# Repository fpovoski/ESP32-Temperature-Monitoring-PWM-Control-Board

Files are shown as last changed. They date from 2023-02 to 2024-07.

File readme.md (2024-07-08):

# VERSION 2.1 UPDATED WITH NEW FEATURES 
### BUY - https://www.tindie.com/products/28875/

## Description
ESP32 based board for temperature monitoring/PWM fan control/addressable LED control in 3D printer enclosures, audio-visual racks, and computer/networking racks. This ESP32 board features, the powerful ESP-WROOM-32E module, with integrated WiFi and Bluetooth functionality (BR/EDR/BLE). The ESP32 is a chip designed with TSMC ultra-low power management technology. The proven ESP32-D0WD-V3 chip is located in the core of the developed module. This board has a USB-C interface for download of firmware and power during development. The board is flashed with an ESPHome image to allow immediate inclusion onto your WiFi network and OTA programming. It also has headers that allow use with conventional D1 Mini style daughter boards and is therefore pin compatible with most accessories. The board has a JST SH connector with I2C and selectable (3.3/5V) power and ground compatible with Adafruit's STEMMA QT/ Sparkfun Qwiic sensors. With optional JST SH to JST PH cable, it also supports STEMMA and Grove interfaces This board also has four Molex KK (PC fan style) that has one 5v driven output, one 5v tolerant input, in addition to fan (typ. 12v) power and ground for 4.5+ amps per connector and up to 10 amps for all four connectors. It also has two, 3-pin screw connector for one-wire devices, each with 3.3v power and ground.

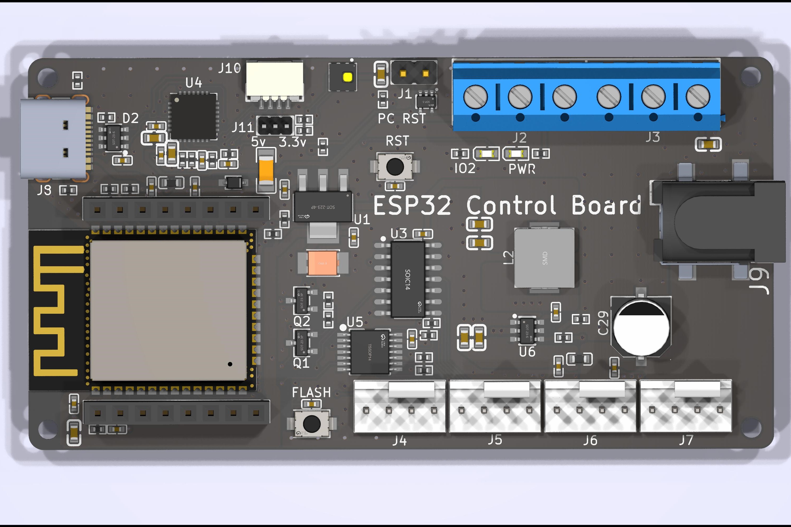
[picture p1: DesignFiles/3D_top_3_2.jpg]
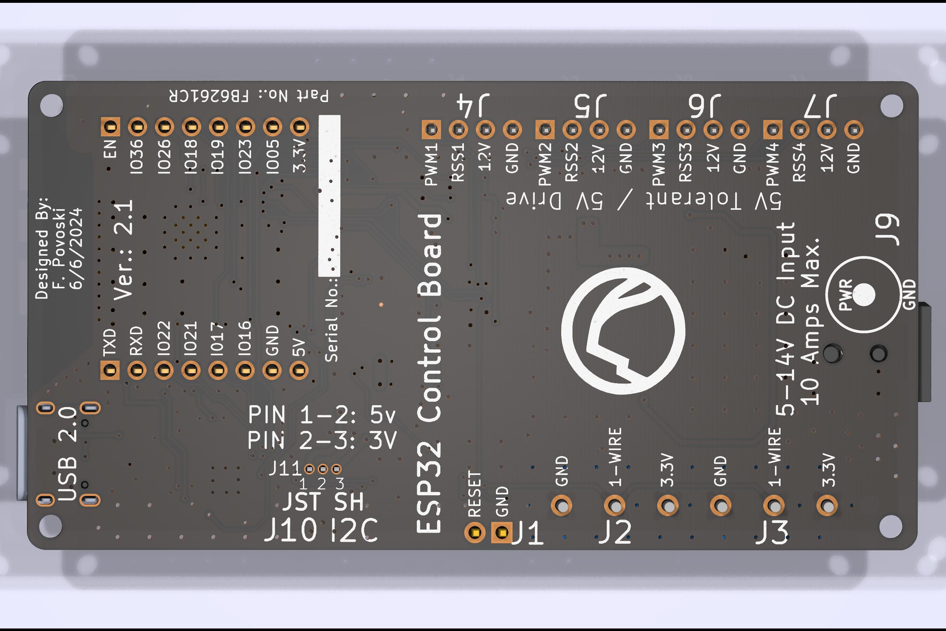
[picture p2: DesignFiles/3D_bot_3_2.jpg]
 

## Specifications:

* Size: 84mm x 44mm with 2mm mounting holes
* Processor: ESP32 on ESP32-WROOM-E module with WiFi and BT V4.2
* Power Input: 12v @ 10 amps max via 5.5mm x 2.1/2.5mm barrel connector or 5v via USB-C connector.
* 10 amp input power.
* On Board Regulation: 5v @ 2 amps switching regulator, 3.3v @ 1.0 amp.
* Onboard AHT20 Temperature and Humidity Sensor.
* Input/Output: One 5v tolerant input (1k pullup) and one 5v driven output, with 12V power (4.5+ amps per conn.) and ground on four, four-pin Molex KK series connectors. Compatible with most PWM PC style fans with speed return. Of course other use cases for these interfaces such as driving LED strings are available.
* I/O: Two screw down three position headers with common one-wire interface as well as 3.3v power and ground.
* I/O: USB 2.0 via USB-C connector using the CP2102N.
* I/O: Standard WEMOS daughter interface on two 1x8 pin headers.
* I/O: JST SH connector w/ I2C/PDM interface 3.3v/5.0v selectable power (compatible with Adafruit's STEMMA QT/ Sparkfun Qwiic sensors).
* I/O: Two-pin 2.54mm header with buffered open collector output.
* Add-ons: Relay - uses GPIO18 mapped to the WEMOS daughter interface.

Please note that some fans especially older ones do not conform with the "Intel 4-Wire PWM Controller Fans" specification. These fans do not stop spinning with a PWM duty cycle of 0% but spin at their minimum RPM. Below is a list of some of these fans currently known to us:
* Corsair 31-002319.
* Delta QFR1212GHE (and very possibly other Delta fans).

A 3D printed enclosure is also available: https://www.tindie.com/products/29364/

## Setup and Configuration

* DO NOT ATTEMPT TO POWER FANS FROM USB-C. Supplied power (5v-14V) to barrel connector
needs to match the voltage of the PWM fan (or other device) you are driving. Board has an onboard
self-resetting flex fuse rated at 12 amps.

* To place on WiFi network use 2.4G phone to connect to "AVFAN1 Fallback Hotspot" with password "esphome1" ("trek6666" in some factory flashes). Once connected to your WiFi network, to access the webpage of
the device browse to http://avfan1.local

* Device is flashed with an exmaple ESPhome binary image that has manual control over fans 
and automatic control which can be enabled based the target temperature setting.  Four temperature
sensors control each of the four PWM fan connectors.
Flashed binary image  has "api:" disabled, MQTT enabled.

* For customization, downlaod the example (flashed) code from 
https://github.com/fpovoski/ESP32-Temperature-Monitoring-PWM-Control-Board/blob/main/ESPhome/avfan1.yaml

* Also update WiFi and MQTT server credentials as required.

* Flash over USB or ethernet. To flash over USB use ESPhome Web Flasher https://web.esphome.io/
with the device powered and connected to your host machine.

* For Dallas style sensors (board preprogrammed with logger level: DEBUG), to get device ID follow
Seach for them in the initial logger output when connected to the USB port using ESPhome Web Flasher.
  - Connect your Dallas sensors with logger: DEBUG enabled (factory flash default).
  - Open the ESPHome webtool, connect to the ECB board, view the "Logs" window, hit "Reset",and search for Dallas scan addresses and replace the below addresses with your unique ones.
  - Example Scan:
  - [18:16:42][D][dallas.sensor:084]:     0x8b3ca8f64935b228 4
  - [18:16:42][D][dallas.sensor:084]:     0x783c0af6490d3628 2
  - [18:16:42][D][dallas.sensor:084]:     0xc13c01f09642c928 1
  - [18:16:42][D][dallas.sensor:084]:     0x043c6ef649772f28 3
  - dallasaddress1: "0xc13c01f09642c928"
  - dallasaddress2: "0x783c0af6490d3628"
  - dallasaddress3: "0x043c6ef649772f28"
  - dallasaddress4: "0x8b3ca8f64935b228"  

* For adding Wemos style boards (i.e., relay) with the case installed  use the long (19mm) provided pins.

## Connector to GPIO Mapping.

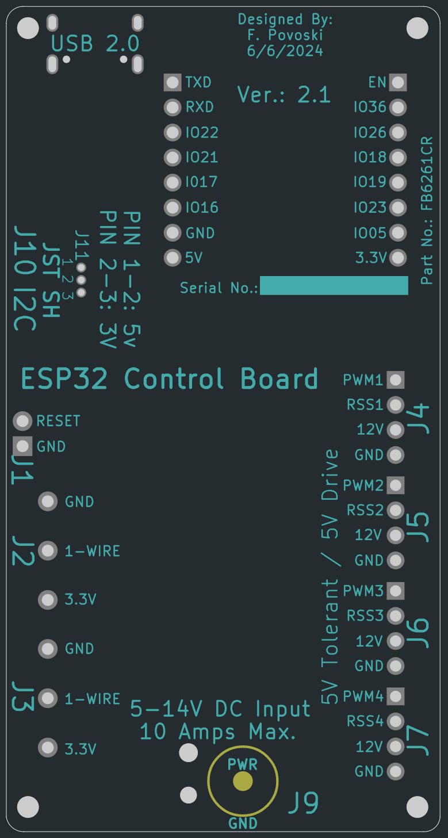
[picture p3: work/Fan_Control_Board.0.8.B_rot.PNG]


### Buffer Open-Collector Ouput on 2.54mm Header J3
| CONNECTOR | PIN1 | PIN2 |
| --- | ---- | ---- |
| J1 | GND | IO26(OC) |

### Dallas One-wire Screw Terminal Connectors J1-J3
| CONNECTOR | PIN1 | PIN2 | PIN3 |
| --- | ---- | ---- | ---- |
| J2 | +3.3V | IO27 | GND |
| J3 | +3.3V | IO27 | GND |

### PWM Fan/LED KK Style Connectors J4-J7
- PIN3 - Input 5V tolerant with 1K pullup resistor
- PIN4 - Output 5V drive.
- PWR - Matches input voltage on J9. Rated to 4.5 amps.
			
| CONNECTOR | PIN1 | PIN2 | PIN3 | PIN4 |
| --- | ---- | ---- | ---- | ---- |
| J4 | GND | PWR | IO33 | IO13 |
| J5 | GND | PWR | IO34 | IO14 |
| J6 | GND | PWR | IO35 | IO25 |
| J7 | GND | PWR | IO39 | IO32 |

### USB-C Connector J8
- USB 2.0, 5V, 2amps.

### Power Jack Connector J9
- +5-14V 12 amps max.
- Directly supplies J4-J7 PWR
- Must match your fan or LED voltage.

| CONNECTOR | Center | Perimeter |
| --- | ---- | ---- |
| J9 | GND | +5-14V | GND |

### I2C/PDM JST SH Connector J10
- Direct Interface for STEMMA and QWIIC boards typically using I2C or PDM.
- Available for other functions than I2C or PDM.
- PWR - Either +3.3V or +5.0V selectable by J11.

| CONNECTOR | PIN1 | PIN2 | PIN3 | PIN4 |
| --- | ---- | ---- | ---- | ---- |
| J10 | GND | PWR | IO21/SDA/PDMDATA | IO22/SCL/PDMCLK |

### Power Selection J11
- Voltage level selection for J10.
- Jumper Pin 1 and 2: +5V
- Jumber Pin 3 and 2: +3.3V

| CONNECTOR | PIN1 | PIN2 | PIN3 |
| --- | ---- | ---- | ---- |
| J11 | +5V | J10.1 | +3.3V |
  
### WeMos D1 Mini Plug P1 and P2

| CONNECTOR | PIN1 | PIN2 | PIN3 | PIN4 | PIN5 | PIN6 | PIN7 | PIN8 |
| --- | ---- | ---- | ---- | ---- | ---- | ---- | ---- | ---- |
| P1 | +5V | GND | IO16 | IO17 | IO21 | IO22 | RXD/IO03 | TXD/IO01 |
| P2 | +3.3V | IO05 | IO23| IO19 | IO18 | IO26 | IO36 | EN |

## Customer Created Projects Utilizing The ECB
Ando Roots: https://www.printables.com/model/702072-1u-rack-fan-shelf

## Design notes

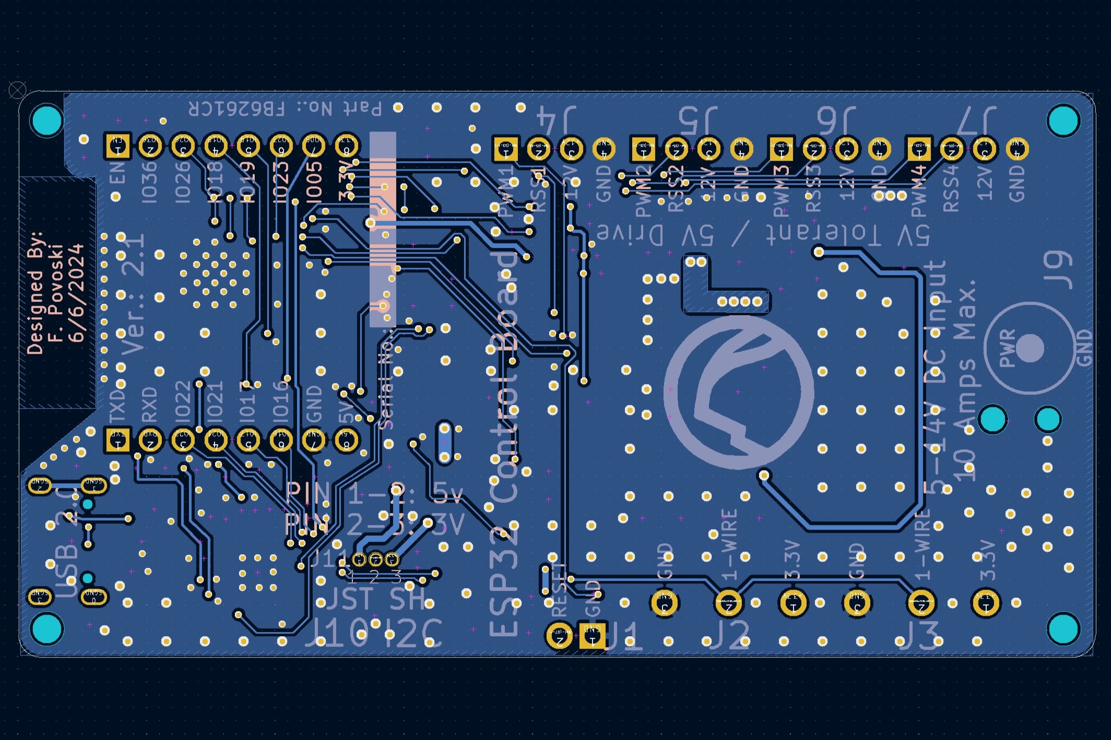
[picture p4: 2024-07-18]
DesignFiles/PCB_bot_3_2.jpg

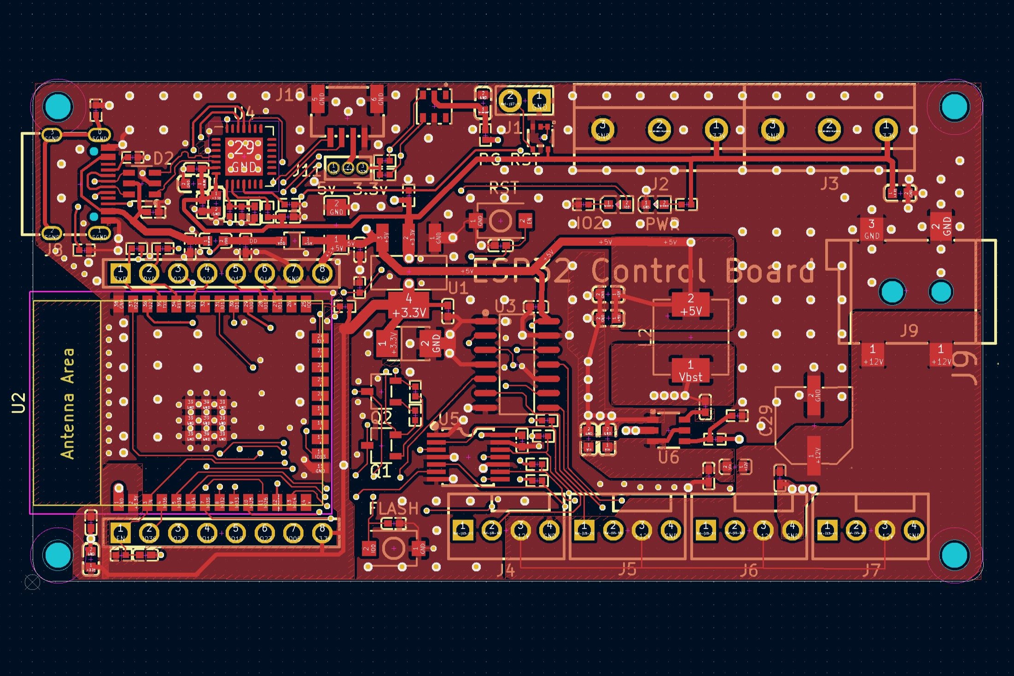
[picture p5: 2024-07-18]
DesignFiles/PCB_top_3_2.jpg

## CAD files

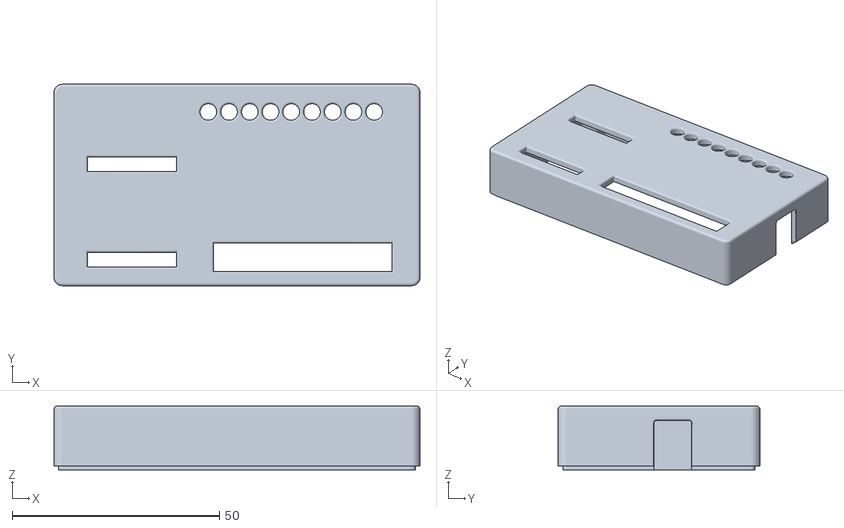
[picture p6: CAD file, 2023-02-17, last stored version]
box 13 top.stl
88.3 x 48.6 x 15.4

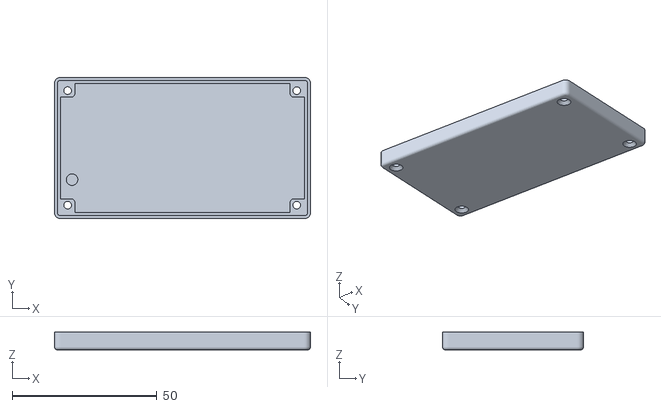
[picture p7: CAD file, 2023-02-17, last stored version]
box 13 bot.stl
88.3 x 48.6 x 6.10

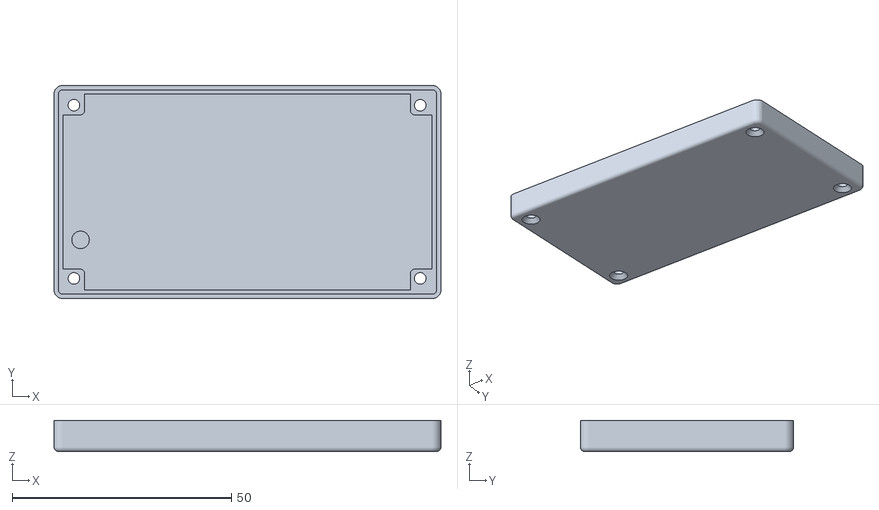
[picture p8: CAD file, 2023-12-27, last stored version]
Enclosure/ECB_bot._V2.stl
88.3 x 48.6 x 7.10

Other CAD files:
Enclosure/ECB_Enclosure_V2.step
Enclosure/NewBoard1 Box.step
Enclosure/ECB_top_V2.stl
Enclosure/Box-Top.stl
Enclosure/ECB_Enclosure_V2.3mf

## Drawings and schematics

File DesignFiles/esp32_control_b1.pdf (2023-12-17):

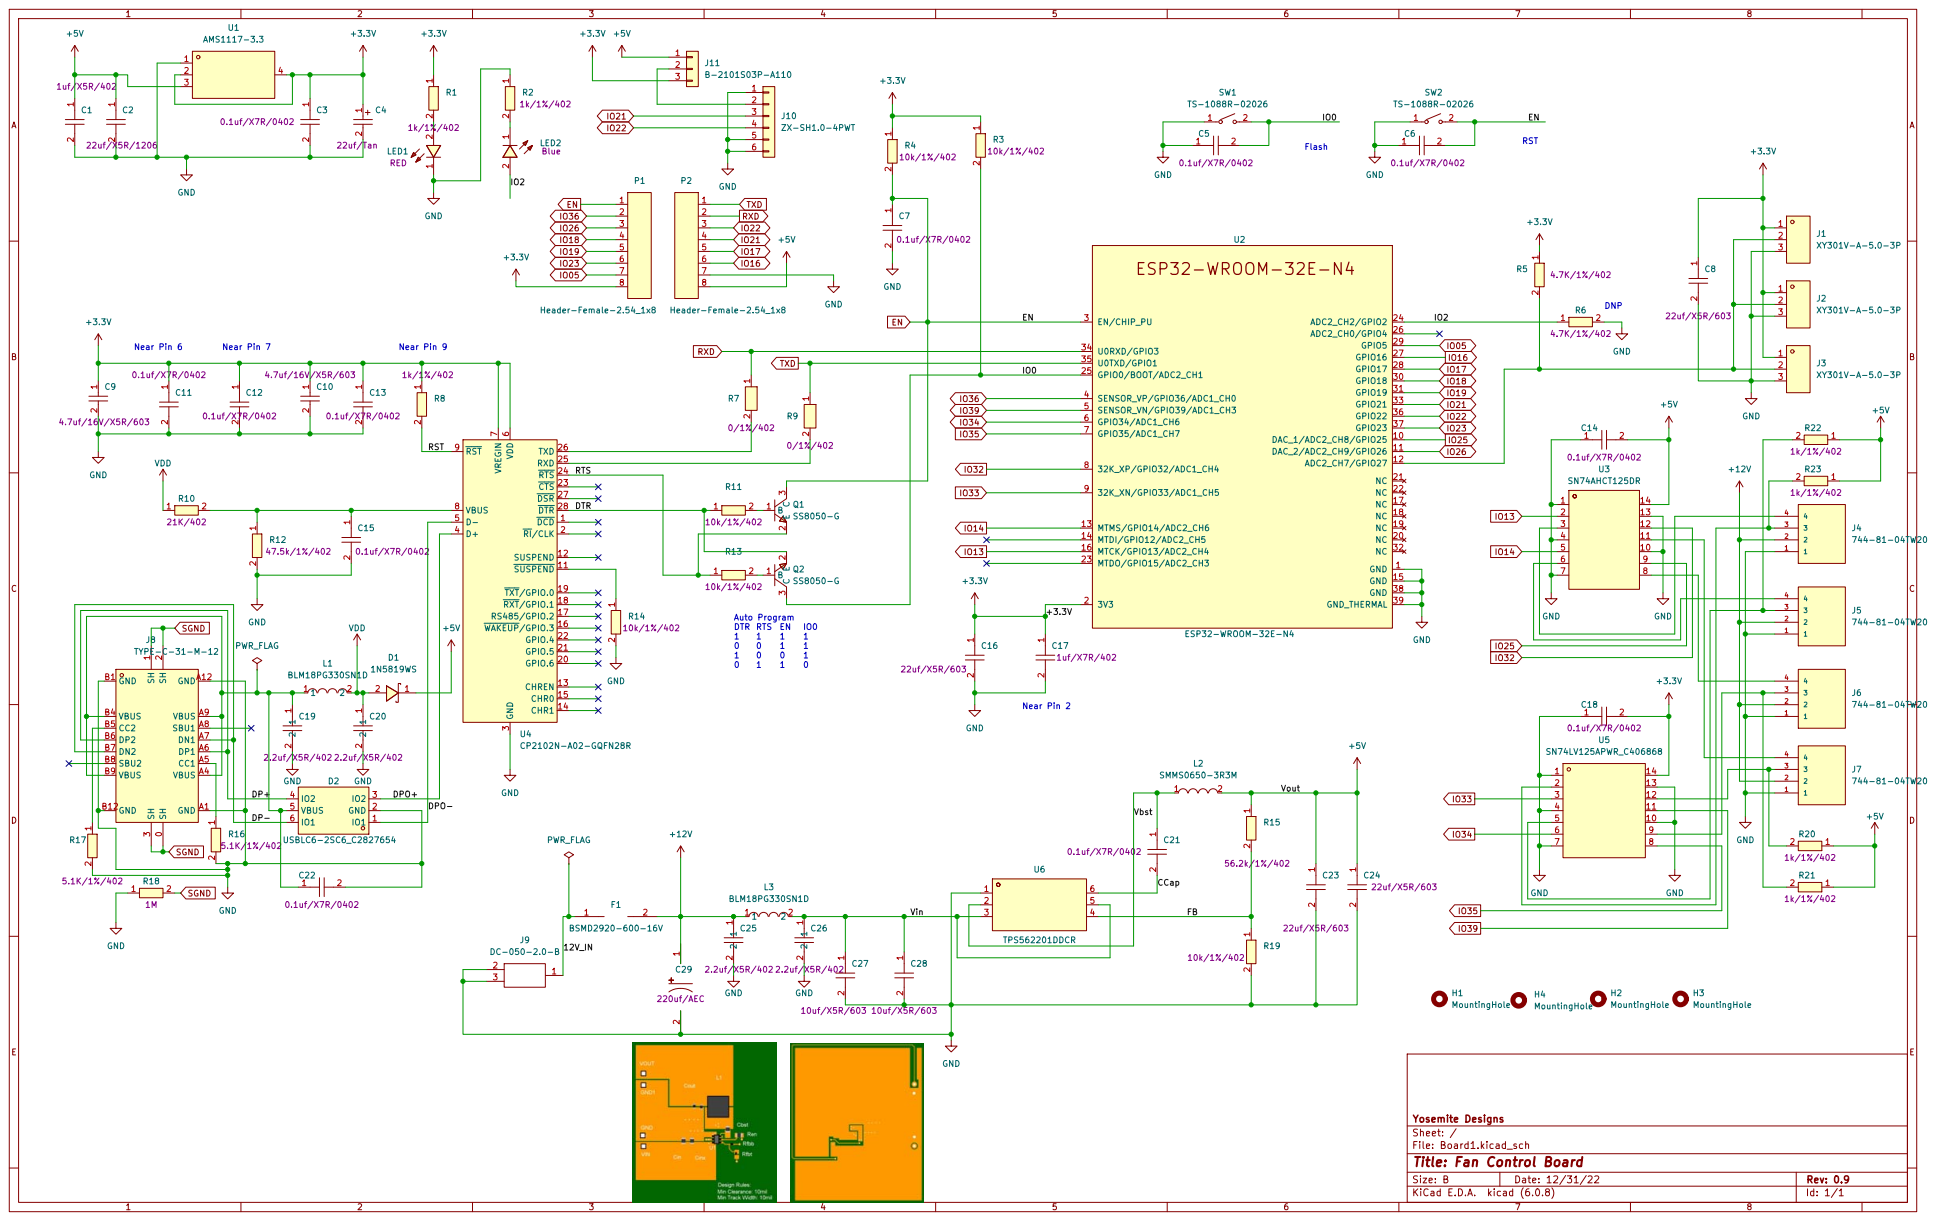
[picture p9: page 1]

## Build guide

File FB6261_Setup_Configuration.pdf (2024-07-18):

## ESP32 Control Board V2.1, Part No. FB6261

For email support: esp32andmore@gmail.com. For text/telephone/WhatsApp support: 1.585.310.1770 See: https://github.com/fpovoski/ESP32-Temperature-Monitoring-PWM-Control-Board

## Setup and Configuration

* Home Assistant Configuration
api:
encryption:
key: "itqzvhZMJj8wuTJX0GTOuL/ffESFROzUlmcO0u2+sfo=" #use your own HA generated Key

* DO NOT ATTEMPT TO POWER FANS FROM USB-C. Supplied power (5v-14V) to barrel connector needs to match the voltage of the PWM fan (or other device) you are driving. Board has an onboard self-resetting flex fuse rated at 10 amps.

* To place on WiFi network use 2.4G phone to connect to "AVFAN1 Fallback Hotspot" with the password "esphome1" ("trek6666" in some factory flashed). Once connected to your WiFi network, to access the webpage of the device browse to http://avfan1.local

* Device is flashed with an example ESPHome binary image that has manual control over fans and automatic control based on the measured temperature and the target temperature setting. Four temperature sensors control each of the four PWM fan connectors. The lambda function in the Dallas Platforms calculates and sets the corresponding fan speed. Flashed binary image has "api:" enabled, MQTT disabled.

* For customization, download the example (flashed) code from https://github.com/fpovoski/ESP32-Temperature-Monitoring PWM-Control-Board (avfan1.yaml). Also update WiFi and MQTT server credentials as required.

* Flash over USB or ethernet. To flash over USB use ESPHome Web Flasher https://web.esphome.io/ with the device powered and connected to your host machine.

* For Dallas style sensors (board preprogrammed with logger level: DEBUG), to get device ID follow
Seach for them in the initial logger output when connected to the USB port using ESPhome Web Flasher. See, avfan1.yaml for instructions.

* For adding Wemos style boards (i.e., relay) with the case installed use the long (19mm) provided pins.

* For voltage selection of JST SH connector (J10) use J11 (+5V - J11.1 to J11.2, +3.3V - J11.3 to J11.2). Despite being able to supply 5v power make sure all your I2C devices are all using 3.3v signaling as it is not a 5v tolerant bus.

Connector to GPIO Mapping
GPIO PIN | CONNECTOR | Input | Output Notes
0 | 25 | | PU | OK | outputs PWM at boot, must be LOW to enter flashing mode
1 | 35 | P2.1 | TX pin OK | debug output at boot
2 | 24 | | OK | OK | conn. to on-board LED, left floating or LOW to enter flashing mode
3 | 34 | P2.2 | OK | RX pin HIGH at boot
4 | 26 | | OK | OK
5 | 29 | P1.7 | OK | OK | outputs PWM signal at boot, strapping pin
6 | 20 | | x | x | connected to the integrated SPI flash
7 | 21 | | x | x | connected to the integrated SPI flash
8 | 22 | | x | x | connected to the integrated SPI flash
9 | 17 | | x | x | connected to the integrated SPI flash
10 | 18 | | x | x | connected to the integrated SPI flash
11 | 19 | | x | x | connected to the integrated SPI flash
12 | 14 | | OK | OK | boot fails if pulled high, strapping pin
13 | 16 | PWM1-(J4) | OK | OK
14 | 13 | PWM2-(J5) | OK | OK | outputs PWM signal at boot
15 | 23 | | OK | OK | outputs PWM signal at boot, strapping pin
16 | 27 | P2.6, SDA_B(AHT20, 0x38) OK | OK

17 | 28 | P2.5, SCL_B(AHT20, 0x38) OK | OK
18 | 30 | P1.4 | OK | OK
19 | 31 | P1.5 | OK | OK
20
21 | 33 | P2.4, SDA_A-(J10) | OK | OK
22 | 36 | P2.3, SCL_A(J10) | OK | OK
23 | 37 | P1.6 | OK | OK
24
25 | 10 | PWM3-(J6) | OK | OK
26 | 11 | P1.3-(J1) | OK | OK
27 | 12 | 1WIRE | OK | OK
32 | 8 | PWM4-(J7) | OK | OK
33 | 9 | RPM1-(J4) | OK | OK
34 | 6 | RPM2-(J5) | OK | input only
35 | 7 | RPM3-(J6) | OK | input only
36 | 4 | P1.2 | OK | input only
39 | 5 | RPM4-(J7) | OK | input only
EN | 3 | P1.1
3.3 | 2 | P1.8
GND | 1 | P2.7
GND | 15
GND | 38
NC | 32
+5 | | P2.8

Open Collector 2.54mm Header Connector
CONN PIN1 | PIN2(labeled RESET)
J1 | GND | IO26

Dallas One-wire Connectors
CONN PIN1 | PIN2 | PIN3
J2 | +3.3V | IO27 | GND
J3 | +3.3V | IO27 | GND
PWM KK Style Headers: | PIN3 - Fan Speed Input, 5V Tolerant, 1K Pullup Resistor
PIN4 - Fan PWM Output, 5V Drive
CONN PIN1 | PIN2 | PIN3 | PIN4
J4 | GND | +5/12V IO33 | IO13
J5 | GND | +5/12V IO34 | IO14
J6 | GND | +5/12V IO35 | IO25
J7 | GND | +5/12V IO39 | IO32

JST SH (STEMMA QT/QWIIC)*
CONN PIN1 | PIN2 | PIN3 | PIN4
J10 | GND | +3.3/5V IO21 | IO22

*1.27MM JUMPER HEADER: PIN1-2 -> +5V, PIN3-2 -> +3.3V
CONN PIN1 | PIN2 | PIN3
J11 | +5V | GND | +3.3V
J8 | USB2.0 on USB-C (USB can be connected when barrel connector power).
J9 | +5/12V 10 amps max. to board and fans. (5-14v range, needs to match devices on J4-J7)

P1 and P2: Standard WEMOS D1 Expansion Header

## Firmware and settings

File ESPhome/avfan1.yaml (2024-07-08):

# Four automatically controlled PWM fan outputs (J4-J7), each set by four target temperatures, maintained by four Dallas sensor's temperatures. MQTT enabled. Home Assistant API disabled. DHCP enabled.
# Other control configurations available with modification of Dallas platform LAMBDA function. Contact us at esp32andmore@gmail.com for no cost customization.
substitutions:
  devicename: avfan1
  fdevicename: AVfan1
  ip: 192.168.0.178 # For static IP adressing

  ssid: !secret wifi_ssid
  password: !secret wifi_password

  alarm_temp: "50" # Threshold for alarm when implemented
  ptemp: "20"
  itemp: "0.1"

# Connect your Dallas sensors with logger: DEBUG enabled (factory flash default).
# Open the ESPHome webtool, connect to the ECB board, view the "Logs" window, hit "Reset",
# and search for Dallas scan addresses and replace the below addresses with your unique ones.
# Example Scan
#[18:16:42][D][dallas.sensor:084]:     0x8b3ca8f64935b228 4
#[18:16:42][D][dallas.sensor:084]:     0x783c0af6490d3628 2
#[18:16:42][D][dallas.sensor:084]:     0xc13c01f09642c928 1
#[18:16:42][D][dallas.sensor:084]:     0x043c6ef649772f28 3
  dallasaddress1: "0xc13c01f09642c928"
  dallasaddress2: "0x783c0af6490d3628"
  dallasaddress3: "0x043c6ef649772f28"
  dallasaddress4: "0x8b3ca8f64935b228"


esphome:
  name: ${devicename}
  friendly_name: ${fdevicename}

  on_boot:
  - priority: 900.0
    then:
      - lambda: |-
          id(cpu_speed) = ESP.getCpuFreqMHz();

esp32:
  board: wemos_d1_mini32
  framework:
    type: arduino

preferences:
  flash_write_interval: 10min
    
wifi:
  ssid: ${ssid}
  password: ${password}
  #fast_connect: true
  #example static IP settings
  #manual_ip:
    #static_ip: ${ip}
    #gateway: 192.168.0.1
    #subnet: 255.255.255.0
    #dns1: 192.168.0.1
    #dns2: 8.8.8.8

  # Enable fallback hotspot (captive portal) in case wifi connection fails
  ap:
    ssid: ${fdevicename} Fallback Hotspot
    password: "esphome1"
    manual_ip:
      static_ip: 192.168.100.2
      gateway: 192.168.100.2
      subnet: 255.255.255.0

    
captive_portal:

ota:
  - platform: esphome
    password: "esphome1"

#safe_mode:

#mqtt:
  #broker: 192.168.0.100   # use your own MQTT server address and credentials
#  username: "john"
#  password: "trek6666"

api:
  encryption:
    key: "itqzvhZMJj8wuTJX0GTOuL/ffESFROzUlmcO0u2+sfo="  #use your own HA generated Key
  
web_server:
  port: 80

time:
  - platform: sntp
    id: current_time

debug:
  update_interval: 5s

logger:
  level: Debug

globals:
  - id: fan1_sum
    type: float
    restore_value: no
    initial_value: '0'
  - id: fan2_sum
    type: float
    restore_value: no
    initial_value: '0'
  - id: fan3_sum
    type: float
    restore_value: no
    initial_value: '0'
  - id: fan4_sum
    type: float
    restore_value: no
    initial_value: '0'
  - id: target1
    type: int
    restore_value: True
    initial_value: '26'
  - id: target2
    type: int
    restore_value: True
    initial_value: '26'
  - id: target3
    type: int
    restore_value: True
    initial_value: '26'
  - id: target4
    type: int
    restore_value: True
    initial_value: '26'
  - id: cpu_speed
    type: int
    restore_value: no
    initial_value: "0"

number:
  - platform: template
    id: set_target_temp_1
    name: ${fdevicename} Target Temp 1
    optimistic: True
    min_value: 15
    max_value: 50
    initial_value: '26'
    step: 1
    restore_value: True
    unit_of_measurement: °C
    device_class: "TEMPERATURE"
    #command_topic: ${devicename}/number/${devicename}_target_temp_1/command  #add for MQTT

  - platform: template
    id: set_target_temp_2
    name: ${fdevicename} Target Temp 2
    optimistic: True
    min_value: 15
    max_value: 50
    initial_value: '26'
    step: 1
    restore_value: true
    unit_of_measurement: °C
    device_class: "TEMPERATURE"
    #command_topic: ${devicename}/number/${devicename}_target_temp_2/command  #add for MQTT

  - platform: template
    id: set_target_temp_3
    name: ${fdevicename} Target Temp 3
    optimistic: True
    min_value: 15
    max_value: 50
    initial_value: '26'
    step: 1
    restore_value: true
    unit_of_measurement: °C
    device_class: "TEMPERATURE"
    #command_topic: ${devicename}/number/${devicename}_target_temp_3/command  #add for MQTT
    
  - platform: template
    id: set_target_temp_4
    name: ${fdevicename} Target Temp 4
    optimistic: True
    min_value: 15
    max_value: 50
    initial_value: '26'
    step: 1
    restore_value: true
    unit_of_measurement: °C
    device_class: "TEMPERATURE"
    #command_topic: ${devicename}/number/${devicename}_target_temp_4/command  #add for MQTT

  - platform: template
    id: set_alarm_temp
    name: ${fdevicename} Alarm Temp
    optimistic: True
    min_value: 15
    max_value: 80
    initial_value: ${alarm_temp}
    step: 1
    restore_value: true
    unit_of_measurement: °C
    device_class: "TEMPERATURE"
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

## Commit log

2023-02-17 Add files via upload
    Enclosure for ESP32-Temperature-Monitoring-PWM-Control-Board STL files
    [box 13 bot.stl, box 13 top.stl]
2023-12-03 Add files via upload
    Added MQTT control to target temperature
2023-12-16 Rename box 13 bot.stl to Enclosure/box 13 bot.stl
    [box 13 bot.stl]
2023-12-16 Rename box 13 top.stl to Enclosure/box 13 top.stl
    [box 13 top.stl]
2023-12-17 Rename Fan Control Board.0.8.B_rot.png to work/Fan Control Board.0.8.B_rot.png
2023-12-17 Rename Fan Control Board.0.8.B_rot.png to Fan_Control_Board.0.8.B_rot.png
2024-02-21 Add files via upload
    enabled relay on GPIO16
2024-04-25 Turns PWM off in auto mode with no demand.
2024-05-07 Add files via upload
    added zero PWM output at lowest setting, added high temperature alarm feature
